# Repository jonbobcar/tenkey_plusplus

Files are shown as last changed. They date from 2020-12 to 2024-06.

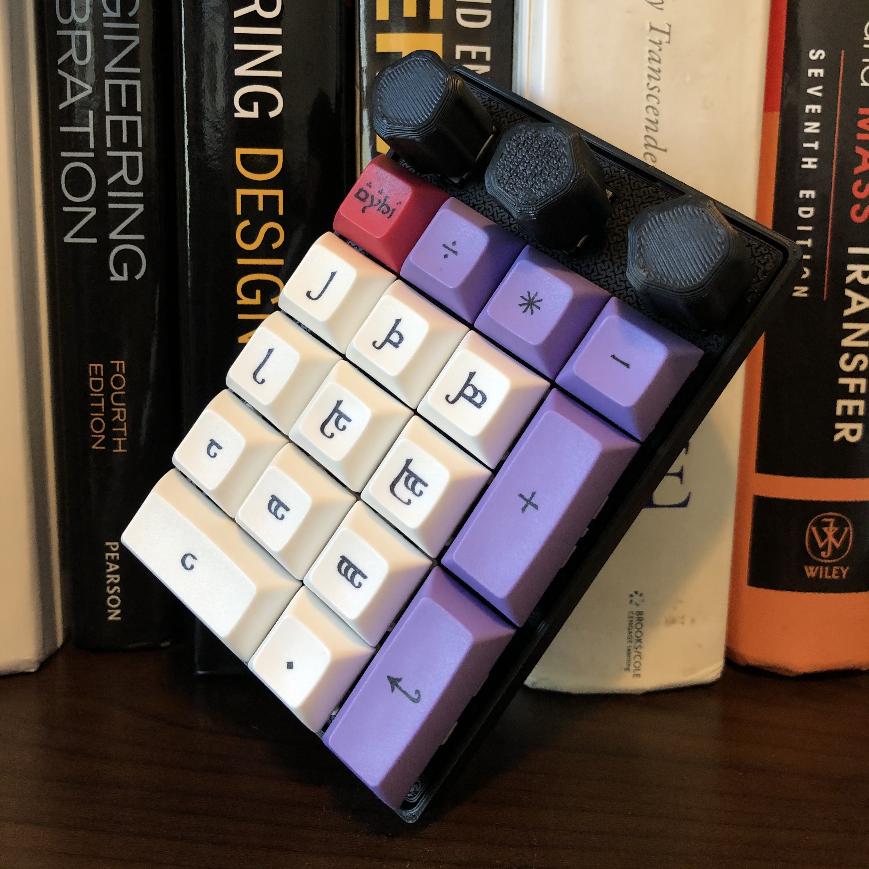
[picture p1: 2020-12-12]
documentation/IMG_4123.jpg

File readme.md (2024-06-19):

# Tenkey++

TK++

Tenkey++ is a USB-C hotswap numpad with the layout of a standard 10-key. Tenkey++ also has three rotary encoders at the top for additional functionality.

* Keyboard Maintainer: [Jonathon](https://github.com/jonbobcar) :: [jonathon@lizardtrick.com](mailto:jonathon@lizardtrick.com)
* Hardware Source Files: [Tenkey++ GitHub Repository](https://github.com/jonbobcar/tenkey_plusplus)
* Hardware Availability: [Tenkey++ on Tindie](https://www.tindie.com/products/lizardtrick/tenkey/)
* QMK Repo Entry: [QMK Link](https://github.com/qmk/qmk_firmware/tree/master/keyboards/lizard_trick/tenkey_plusplus)

Make example for default layout (set up QMK build environment first):

    make lizard_trick/tenkey_plusplus:default
    
Default Layout:

TK++_Default
    
See the [build environment setup](https://docs.qmk.fm/#/getting_started_build_tools) and the [make instructions](https://docs.qmk.fm/#/getting_started_make_guide) for more information. Brand new to QMK? Start with the [Complete Newbs Guide](https://docs.qmk.fm/#/newbs).

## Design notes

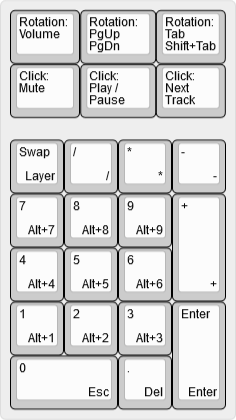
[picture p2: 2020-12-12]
documentation/tenkey++_macro.png

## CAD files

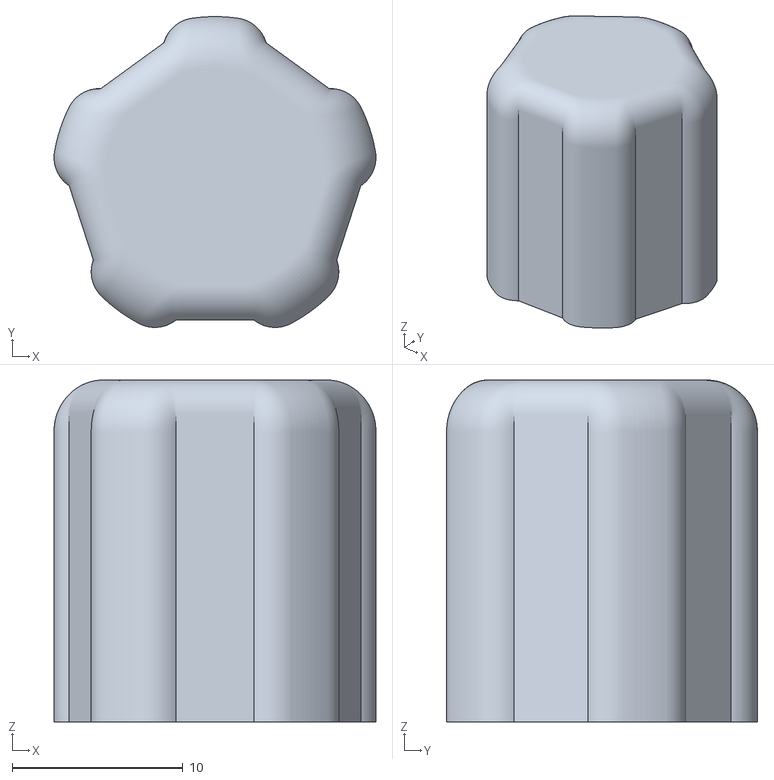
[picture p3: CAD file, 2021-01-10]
mechanical/encoder_knob_knurled.stl
18.8 x 18.2 x 20.0

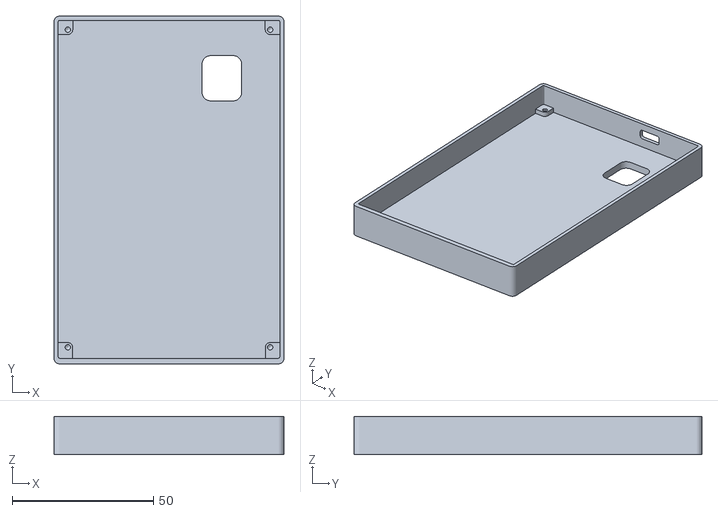
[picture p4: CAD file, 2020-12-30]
mechanical/tenkey_pp_case.stl
81.4 x 123.1 x 13.6

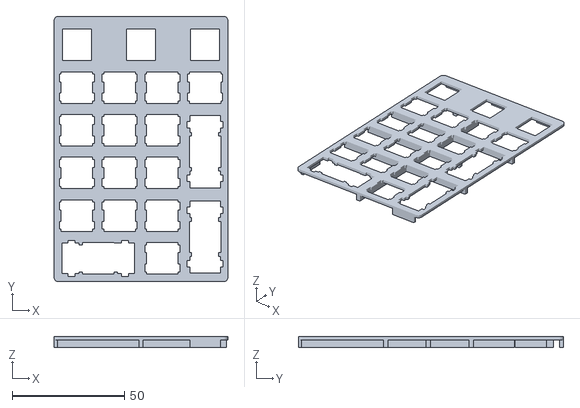
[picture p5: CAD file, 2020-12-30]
mechanical/tenkey_pp_plate.stl
77.4 x 118.1 x 5.00

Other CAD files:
mechanical/tenkey_plusplus_case.f3d
mechanical/tenkey_plusplus_plate.f3d

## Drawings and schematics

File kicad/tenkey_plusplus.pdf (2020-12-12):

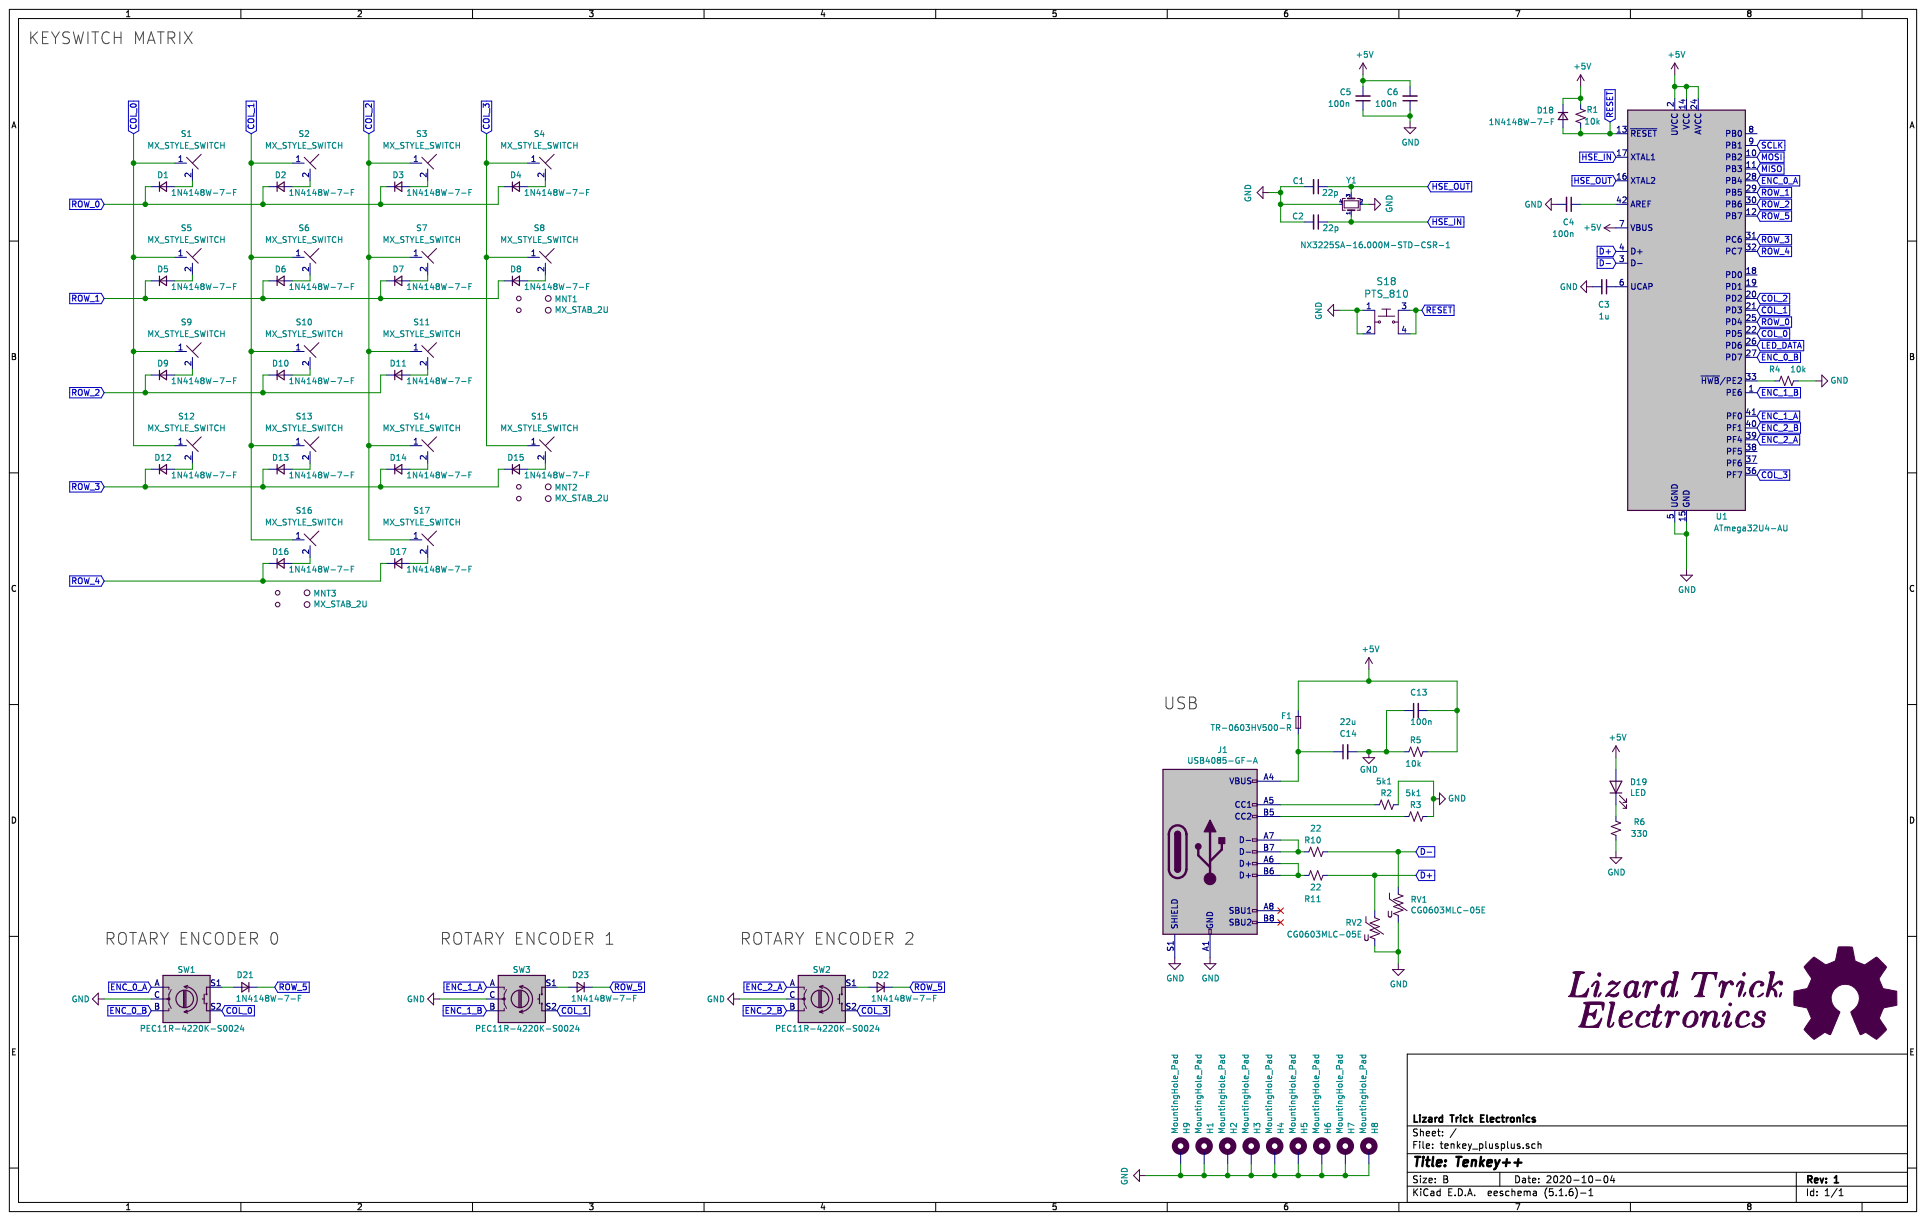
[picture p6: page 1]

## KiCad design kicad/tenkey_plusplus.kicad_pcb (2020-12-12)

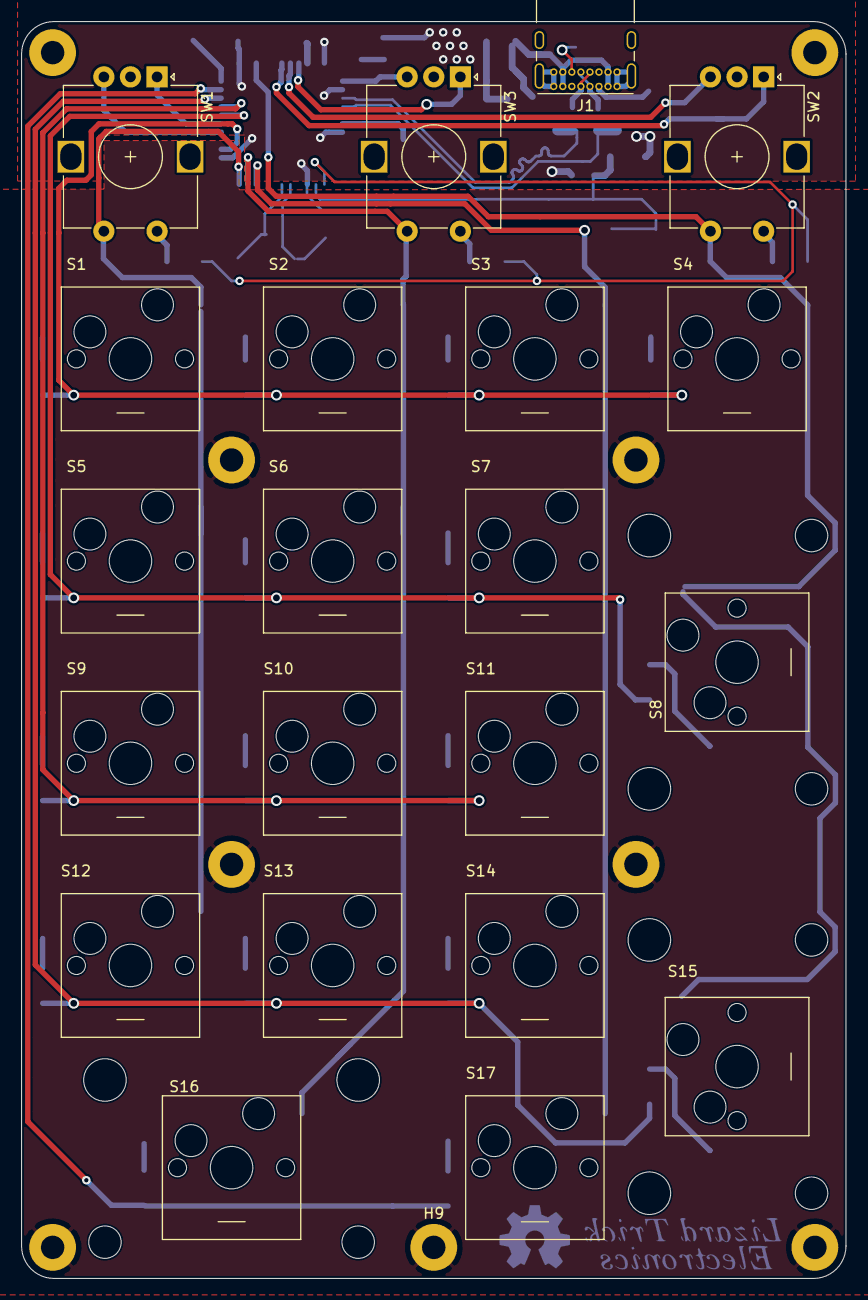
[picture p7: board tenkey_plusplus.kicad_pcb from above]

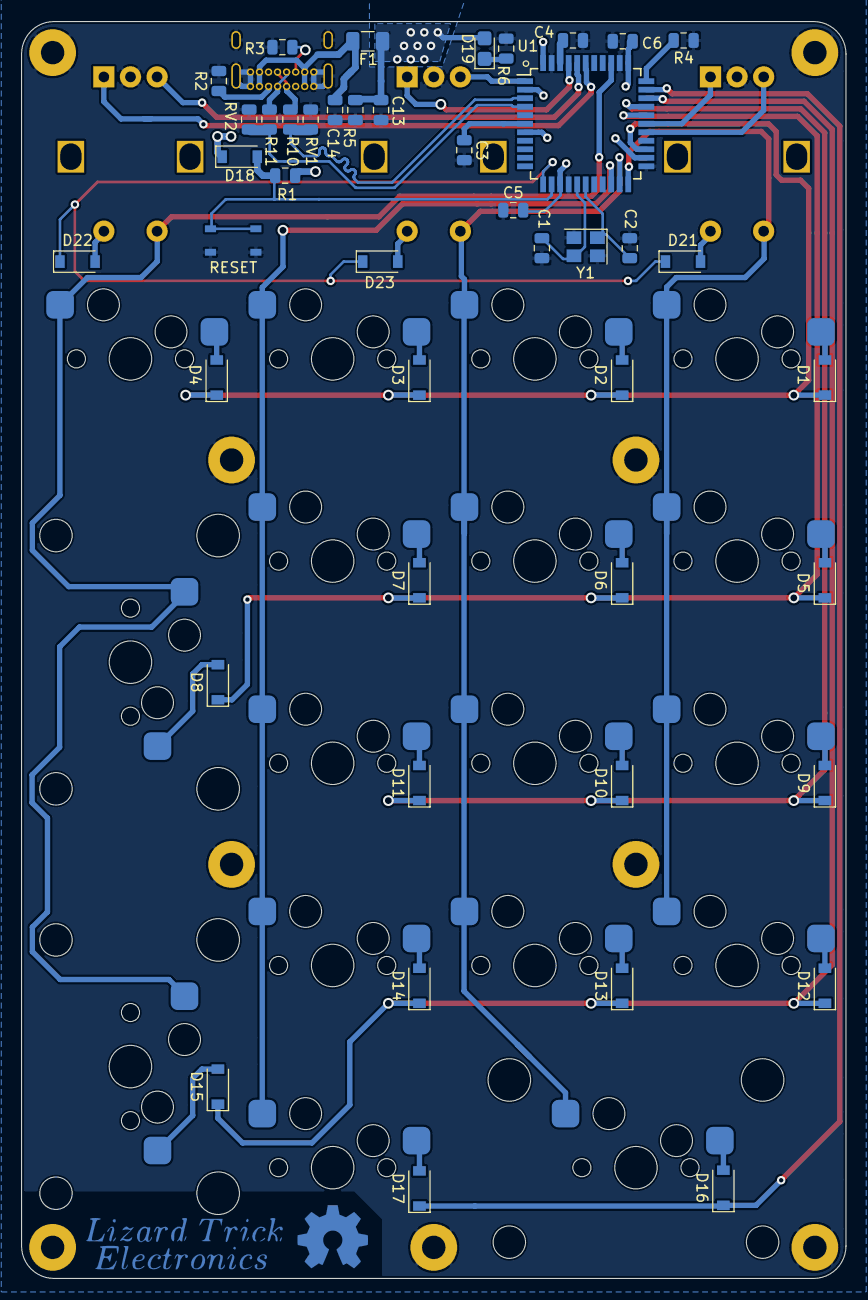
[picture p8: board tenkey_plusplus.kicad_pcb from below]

Board: 2 copper layers, 77.5 x 118.1 mm, 79 parts (46 on the bottom side), 52 nets.

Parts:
C1, C2: 22p; C_0805_2012Metric
C3: 1u; C_0805_2012Metric
C4, C5, C6, C13: 100n; C_0805_2012Metric
C14: 22u; C_0805_2012Metric
D1, D2, D3, D4, D5, D6, D7, D8, D9, D10, D11, D12, D13, D14, D15, D16, D17, D18, D21, D22, D23: 1N4148W-7-F; D_SOD-123
D19: LED; LED_0805_2012Metric_Castellated
F1: TR-0603HV500-R; Fuse_1206_3216Metric
H1, H2, H3, H4, H5, H6, H7, H8, H9: MountingHole_Pad; MountingHole_2.2mm_M2_Pad
J1: USB4085-GF-A; USB_C_Receptacle_GCT_USB4085
LOGO1: Lizard_Logo; lizard_trick
LOGO2: Logo_Open_Hardware_Large; OSHW-Symbol_6.7x6mm_Copper
MNT1, MNT2, MNT3: MX_STAB_2U; mx_stab_2u
R1, R4, R5: 10k; R_0805_2012Metric
R2, R3: 5k1; R_0805_2012Metric
R6: 330; R_0805_2012Metric
R10, R11: 22; R_0805_2012Metric
RV1, RV2: CG0603MLC-05E; R_0805_2012Metric
S1, S2, S3, S4, S5, S6, S7, S8, S9, S10, S11, S12, S13, S14, S15, S16, S17: MX_STYLE_SWITCH; hotswap_keyswitch
S18: PTS_810; PTS_180_Tactile_Switch
SW1, SW2, SW3: PEC11R-4220K-S0024; RotaryEncoder_Bourns_PEC11L
U1: ATmega32U4-AU; TQFP-44_10x10mm_P0.8mm
Y1: NX3225SA-16.000M-STD-CSR-1; Crystal_SMD_3225-4Pin_3.2x2.5mm

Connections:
+5V: C5.2, C6.2, C13.2, D18.1, D19.2, F1.2, R1.2, R5.1, U1.2, U1.7, U1.14, U1.24, U1.34, U1.44
COL_0: S1.1, S5.1, S9.1, S12.1, SW1.S2, U1.22
COL_1: S2.1, S6.1, S10.1, S13.1, S16.1, SW3.S2, U1.21
COL_2: S3.1, S7.1, S11.1, S14.1, S17.1, U1.20
COL_3: S4.1, S8.1, S15.1, SW2.S2, U1.36
D+: R11.1, RV2.1, U1.4
D-: R10.1, RV1.1, U1.3
ENC_0_A: SW1.A, U1.28
ENC_0_B: SW1.B, U1.27
ENC_1_A: SW3.A, U1.41
ENC_1_B: SW3.B, U1.1
ENC_2_A: SW2.A, U1.39
ENC_2_B: SW2.B, U1.40
GND: C1.2, C2.2, C3.2, C4.2, C5.1, C6.1, C13.1, C14.2, H1.1, H2.1, H3.1, H4.1, H5.1, H6.1, H7.1, H8.1, H9.1, J1.A1, J1.A12, J1.B1, J1.B12, J1.S1, R2.1, R3.1, R4.1, R5.2, R6.1, RV1.2, RV2.2, S18.1, S18.2, SW1.C, SW2.C, SW3.C, U1.5, U1.15, U1.23, U1.35, U1.43, Y1.2, Y1.4
HSE_IN: C2.1, U1.17, Y1.1
HSE_OUT: C1.1, U1.16, Y1.3
unnamed: C3.1, U1.6
unnamed: C4.1, U1.42
unnamed: C14.1, F1.1, J1.A4, J1.A9, J1.B4, J1.B9
unnamed: D1.2, S1.2
unnamed: D2.2, S2.2
unnamed: D3.2, S3.2
unnamed: D4.2, S4.2
unnamed: D5.2, S5.2
unnamed: D6.2, S6.2
unnamed: D7.2, S7.2
unnamed: D8.2, S8.2
unnamed: D9.2, S9.2
unnamed: D10.2, S10.2
unnamed: D11.2, S11.2
unnamed: D12.2, S12.2
unnamed: D13.2, S13.2
unnamed: D14.2, S14.2
unnamed: D15.2, S15.2
unnamed: D16.2, S16.2
unnamed: D17.2, S17.2
unnamed: D19.1, R6.2
unnamed: D21.2, SW1.S1
unnamed: D22.2, SW2.S1
unnamed: D23.2, SW3.S1
unnamed: J1.A5, R2.2
unnamed: J1.A6, J1.B6, R11.2
unnamed: J1.A7, J1.B7, R10.2
unnamed: J1.B5, R3.2
unnamed: R4.2, U1.33
RESET: D18.2, R1.1, S18.3, S18.4, U1.13
ROW_0: D1.1, D2.1, D3.1, D4.1, U1.25
ROW_1: D5.1, D6.1, D7.1, D8.1, U1.29
ROW_2: D9.1, D10.1, D11.1, U1.30
ROW_3: D12.1, D13.1, D14.1, D15.1, U1.31
ROW_4: D16.1, D17.1, U1.32
ROW_5: D21.1, D22.1, D23.1, U1.12

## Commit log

2020-12-12 Initial Commit
    Committing KiCad and documentation files.
    [bom.ods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]
2020-12-30 adding case and plate .stl files
    [encoder knob knurled.stl, tenkey_pp_case.stl, tenkey_pp_plate.stl]
2021-01-07 updated knurled knob design
    [encoder knob knurled.stl, encoder_knob_knurled.stl]
2021-07-10 added f3d files for case and plate
    [Tenkey PlusPlus Case.f3d, Tenkey PlusPlus Plate.f3d]
2021-07-10 fixed directory issue and moved plate+case to mechanical directory
    [tenkey_plusplus_case.f3d, tenkey_plusplus_plate.f3d]
